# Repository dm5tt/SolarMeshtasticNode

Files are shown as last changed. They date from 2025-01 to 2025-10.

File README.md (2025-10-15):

**Warning:** 

This thing will get a big overhaul (better access to bus interfaces, improved outlines, etc.) as soon as the new TI BQ25630 charging controller will be released end of the year.  

The design will be much less complex  as we can get all power relevant data (solar/battery voltage, currents) by just querying the charger IC via I2C. 

Also the BOM will be much compacter as no voltage dividers will be need.

---

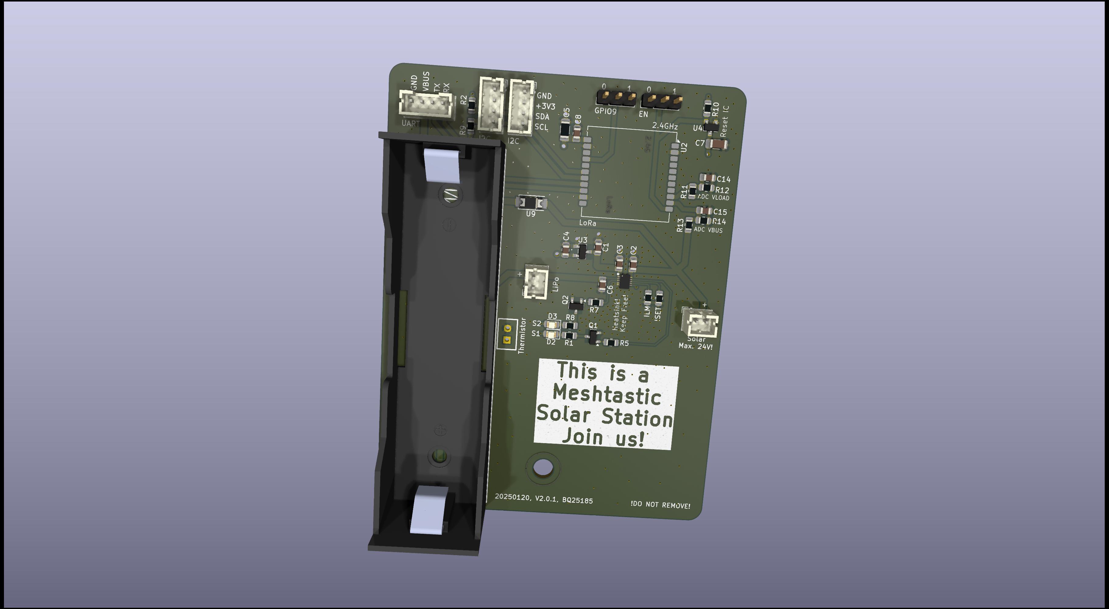
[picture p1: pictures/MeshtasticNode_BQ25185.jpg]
MeshtasticRouterNode


## What is this thing?

This is a Meshtastic solar node based on the [Heltec HT-CT62](https://resource.heltec.cn/download/HT-CT62/HT-CT62(Rev1.1).pdf) and the (new) linear solar charge controller [TI BQ25185](https://www.ti.com/lit/ds/symlink/bq25185.pdf).

Features of this PCB

 - Solar Input up to 18V (24V survival)
 - 3A maximum load
 - 1A maximum charge current
 - Pseudo-MPPT (VINDPM)
 - Power Path (= if the battery is fully charged and there's enough solar power the device is getting powered directly from solar. During sunrise and sunset it can mix the sources.)
 - Two ADC signals for getting VLOAD and  VBUS voltage using voltage dividers
 - 3.7V LiPo either via 18650 block or JST-PH 2.0 connector
 - Low power LDO [HEERMICR HE9073A30MR](https://www.lcsc.com/datasheet/lcsc_datasheet_2304140030_HEERMICR-HE9073A30MR_C723792.pdf)
 - Brown-out Reset IC ([Diodes Incorporated APX803L05-32SA-7](https://wmsc.lcsc.com/wmsc/upload/file/pdf/v2/lcsc/2304140030_Diodes-Incorporated-APX803L05-32SA-7_C2067928.pdf)) at 3.2V which senses the voltage *before* the LDO 

Combined with a solar panel this device can be placed in remote areas to cover a wide range.

*If you want to use the Reset IC*

Do not bridge the "EN" pin headers. The signal of this IC is "weak" -  it can be overruled by a jumper without destroying the board.

# Where can I get all the stuff?

Heltec HT-CT62: Aliexpress

TI BQ25185: Mouser or Digikey

PCB: You can load the Kicad project file and then export the manufacturing files using the plugins. Just throw them into JLCPCB and order them.

Everything else can be ordered from LCSC.

Due to strict legislation, it is not planned to offer ready-made circuit boards or kits here. Sorry.

# Meshtastic, ESP32 and Power Saving. How?

*Warning 1* 

By enabling "Power Saving" you will loose *all* regular telemetry (Sensors, Battery Voltages, etc.)! The battery voltage can be polled manually using the Python lib.

I reported this a bug but it was rejected.

*Warning 2* 

You also will not be able to configure it by serial port anymore! You have a short period after power cycling it. Use the "meshtastic" Python script as it waits for a while.

### Router Role

1. Enable "Power Saving" (is activated by default if using Router role)

2. When configuring the device you should set the "Minimum Wake Interval" from 10 seconds to 1 second.

3. Switch Bluetooth and Wifi off! They suck power like crazy.

### Client Role

This is more tricky as per default it doesn't switch into "Light Sleep" as several delays are blocking it.

You also have to decrease "Wait Bluetooth Seconds" and "Screen on Seconds" to 1 second.

Then configure is like a "Router".

# Do I have to modify the Software and configuration?

I'm keeping a more or less outdated branch von the Meshtastic firmware on `git@github.com:dm5tt/meshtastic-firmware.git` in the branch `solarmeshtasticnode`. If you want a fresher version you must rebase it yourself.

# Evaluation

[Evaluation, PCB v0.2 (CR123A)](./EVALUATION-v02.md)

[Evaluation, PCB v2.0.0 (18650)](./EVALUATION-v200.md)

# FAQ

*The HT-CT62 uses a ESP32C3. Thats not Low Power!!!*

Meshtastic  supports the "Power Saving" mode on the ESP32 where the entire   device stays  in the light sleep mode until it gets a interrupt signal from the LoRa modem. In that phase CPU will consume around ~800uA while sleeping. Including LoRa RX that's a idle current draw around is 5-6mA.

Warning, again: switching on BLE or even Wifi will make the ESP32 burn a crazy amount of energy. 

For sunny regions (Portugal, Spain, etc.) a 6V panel is enough. For central Europe (like Germany) a 12V or higher solar panel is recommended for surviving the winter.

Still far away from the RAK4631 with a Nordic microcontroller. But who cares? During the day you will have a positive power budget so the entire devices runs on solar energy and recharges its battery even with small cells.

*It's not really that cheap either!*

Yep. It's expensive if you build only 1 device. But the costs dramatically drop if think of building 5-10 of them as you can mass order everything (PCBs, Components from LCSC and so own).

*The TI BQ25185 uses a linear regulator to create the voltage before the LDO. That will be inefficient for solar panels above 6V.*

Yes. It's very inefficient if it's running with the power path enabled (= direct solar pass-through) as the device has to burn off a lot of voltage from the panel. During battery runtime the difference is way lower which is acceptable.

It maybe cause unneccesary heat during the winter time where small 18V solar panels would be a great benefit. But for 6V panels it's a within acceptable ranges.

I'm planing to build a new generation of the SolarMeshtasticNode with the upcoming [TI BQ25630](https://www.ti.com/lit/ds/symlink/bq25630.pdf?ts=1755932677893). It has an integrated ADC (which allows us to get rid of all power dividers) and also has a  very efficient DC DC buck architecture. Price wise it will be around $2 which is still very acceptable.

*Why are you using a 3.0V and not a 3.3V LDO?*

This gives us more runtime by only loosing 1-2dB TX power from the LoRa module.  

With a 3.3V LDO the device will switch off around ~3.5V - with 3.0V LDO it can survive down to 3.2V.

# Warning

LED circuit for STAT1 and STAT2 aren't tested. The TI BQ25185 uses 1.8V for the status pins so the LEDs must be switched via a transistor against the 3.3V supply voltage.

# License

CERN OHL v2 – Strongly Reciprocal (S)

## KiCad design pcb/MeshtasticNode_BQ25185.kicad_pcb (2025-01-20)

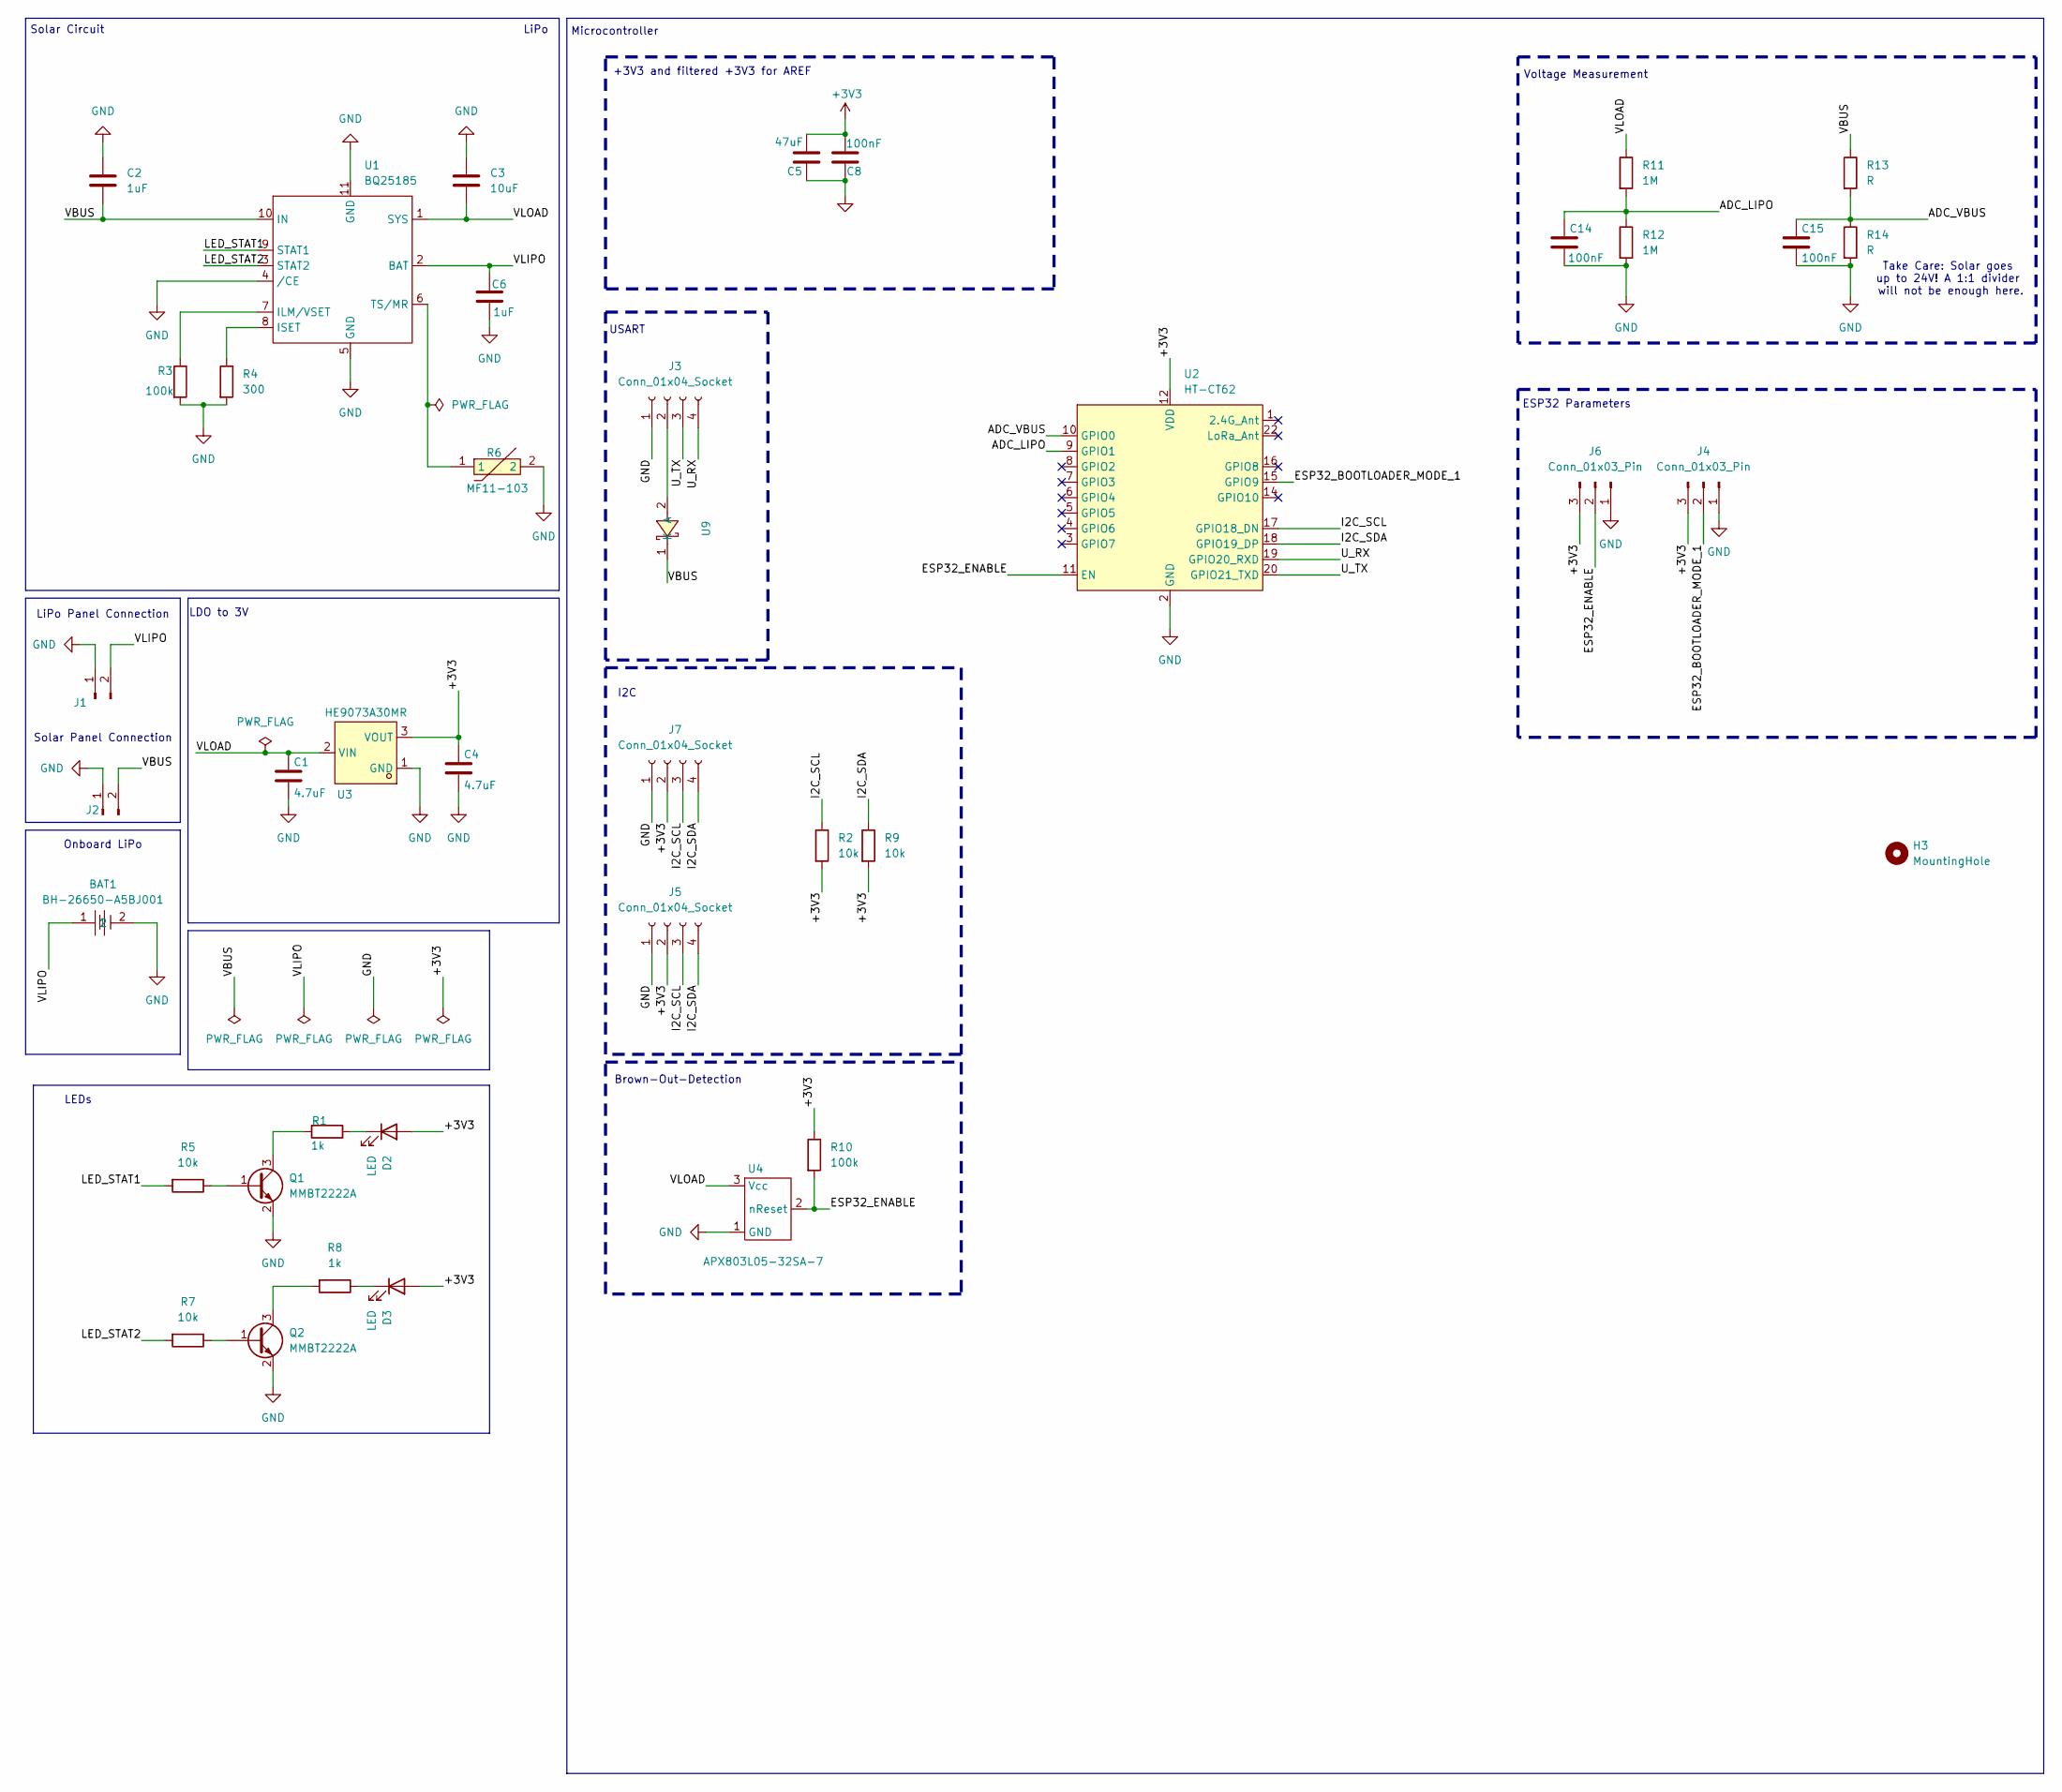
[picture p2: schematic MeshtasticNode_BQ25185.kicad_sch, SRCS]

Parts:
BAT1: BH-26650-A5BJ001; BAT-TH_BH-18650-A1AJ005; LCSC Part C6937119
C1, C4: 4.7uF; C_0805_2012Metric_Pad1.18x1.45mm_HandSolder
C2, C6: 1uF; C_0805_2012Metric_Pad1.18x1.45mm_HandSolder
C3: 10uF; C_0805_2012Metric_Pad1.18x1.45mm_HandSolder
C5: 47uF; R_1206_3216Metric_Pad1.30x1.75mm_HandSolder
C8, C14, C15: 100nF; C_0805_2012Metric_Pad1.18x1.45mm_HandSolder
D2, D3: LED; LED_0805_2012Metric_Pad1.15x1.40mm_HandSolder
H3: MountingHole; MountingHole_4.3mm_M4_DIN965
J1, J2: Conn_01x02_Socket; JST_PH_B2B-PH-K_1x02_P2.00mm_Vertical
J3, J5, J7: Conn_01x04_Socket; JST_PH_B4B-PH-K_1x04_P2.00mm_Vertical
J4, J6: Conn_01x03_Pin; PinHeader_1x03_P2.54mm_Vertical
Q1, Q2: MMBT2222A; SOT-23
R1, R8: 1k; R_0805_2012Metric_Pad1.20x1.40mm_HandSolder
R2, R5, R7, R9: 10k; R_0805_2012Metric_Pad1.20x1.40mm_HandSolder
R3, R10: 100k; R_0805_2012Metric_Pad1.20x1.40mm_HandSolder
R4: 300; R_0805_2012Metric_Pad1.20x1.40mm_HandSolder
R6: MF11-103; RES-TH_L6.5-W4.0-P2.50-D0.5; LCSC Part C70913
R11, R12: 1M; R_0805_2012Metric_Pad1.20x1.40mm_HandSolder
R13, R14: R; R_0805_2012Metric_Pad1.20x1.40mm_HandSolder
U1: BQ25185; SON40P220X200X80-11N
U2: HT-CT62; Heltec_HT-CT62
U3: HE9073A30MR; SOT-23-3_L2.9-W1.6-P1.90-LS2.8-BR-CW; LCSC Part C723793
U4: APX803L05-32SA-7; SOT23-3
U9: SS26_C5350986; SMA_L4.3-W2.6-LS5.1-RD; LCSC Part C5350986

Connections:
+3V3: C4.1, C5.2, C8.2, D2.2 (A), D3.2 (A), J4.3, J5.2, J6.3, J7.2, R2.2, R9.2, R10.1, U2.12 (VDD), U3.3 (VOUT)
/ADC_LIPO: C14.1, R11.2, R12.1, U2.9 (GPIO1)
/ADC_VBUS: C15.1, R13.2, R14.1, U2.10 (GPIO0)
/ESP32_BOOTLOADER_MODE_1: J4.2, U2.15 (GPIO9)
/ESP32_ENABLE: J6.2, R10.2, U2.11 (EN), U4.2 (nReset)
/I2C_SCL: J5.3, J7.3, R2.1, U2.17 (GPIO18_DN)
/I2C_SDA: J5.4, J7.4, R9.1, U2.18 (GPIO19_DP)
/LED_STAT1: R5.2, U1.9 (STAT1)
/LED_STAT2: R7.2, U1.3 (STAT2)
/U_RX: J3.4, U2.19 (GPIO20_RXD)
/U_TX: J3.3, U2.20 (GPIO21_TXD)
/VBUS: C2.2, J2.2, R13.1, U1.10 (IN), U9.1 (K)
/VLIPO: BAT1.1, C6.1, J1.2, U1.2 (BAT)
/VLOAD: C1.1, C3.2, R11.1, U1.1 (SYS), U3.2 (VIN), U4.3 (Vcc); also elsewhere on the board
GND: BAT1.2, C1.2, C2.1, C3.1, C4.2, C5.1, C6.2, C8.1, C14.2, C15.2, J1.1, J2.1, J3.1, J4.1, J5.1, J6.1, J7.1, Q1.2 (E), Q2.2 (E), R3.2, R4.2, R6.2, R12.2, R14.2, U1.4 (/CE), U1.5 (GND), U1.11 (GND), U2.2 (GND), U2.13 (GND), U2.21 (GND), U3.1 (GND), U4.1 (GND); also elsewhere on the board
unnamed: D2.1 (K), R1.1
unnamed: D3.1 (K), R8.1
unnamed: J3.2, U9.2 (A)
unnamed: Q1.1 (B), R5.1
unnamed: Q1.3 (C), R1.2
unnamed: Q2.1 (B), R7.1
unnamed: Q2.3 (C), R8.2
unnamed: R3.1, U1.7 (ILM/VSET)
unnamed: R4.1, U1.8 (ISET)
unnamed: R6.1, U1.6 (TS/MR)

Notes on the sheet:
ESP32 Parameters
Solar Circuit
Microcontroller
USART
Voltage Measurement
LiPo
LiPo Panel Connection
+3V3 and filtered +3V3 for AREF
Brown-Out-Detection
Onboard LiPo
Solar Panel Connection
LDO to 3V
I2C
Take Care: Solar goes up to 24V! A 1:1 divider will not be enough here.
LEDs

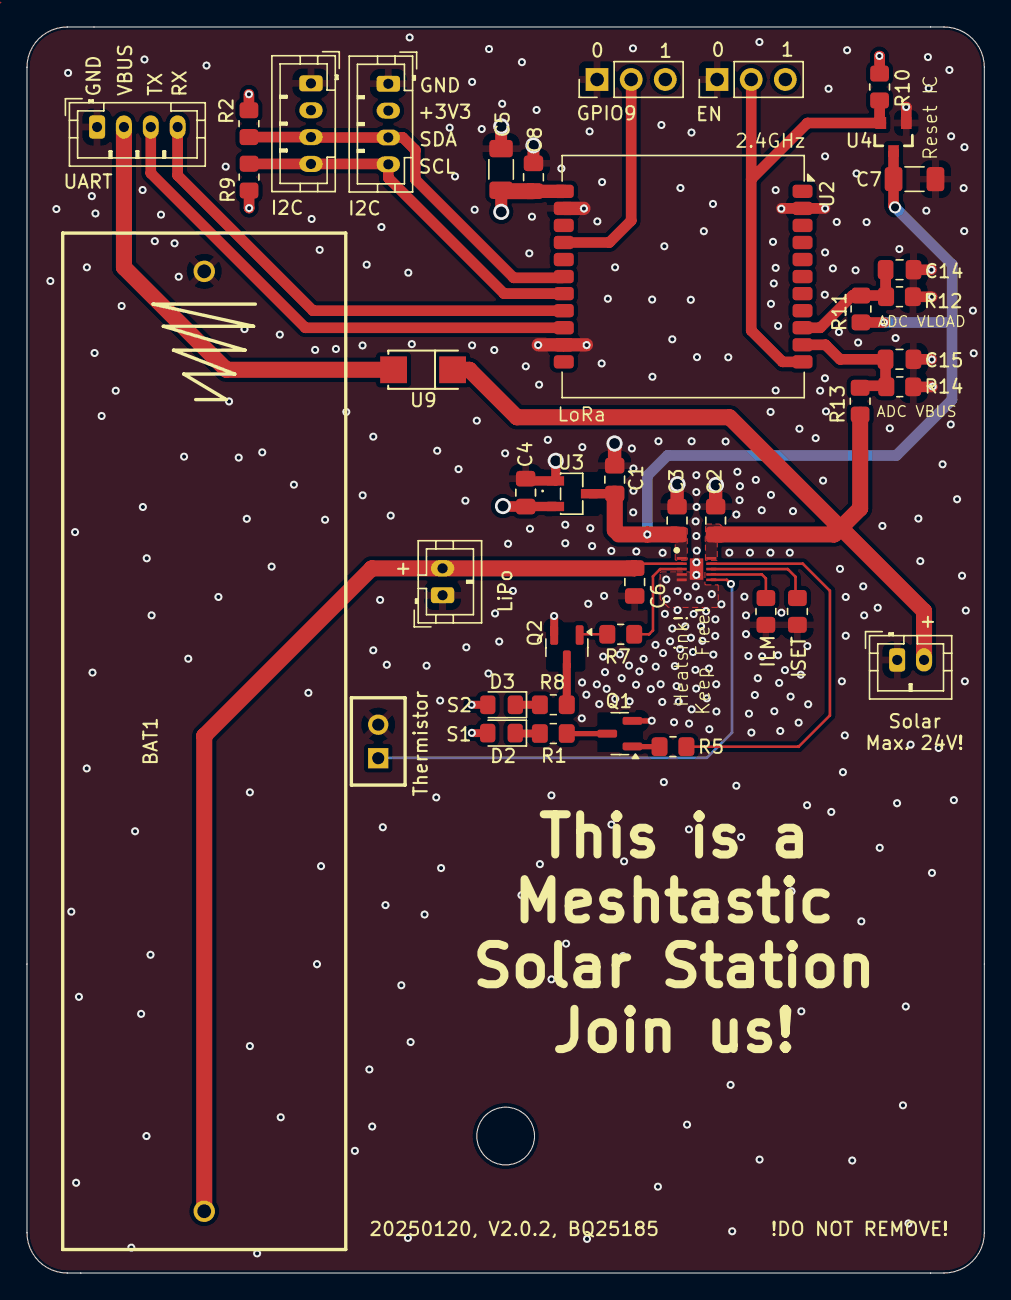
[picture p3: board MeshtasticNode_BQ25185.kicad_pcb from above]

Board: 4 copper layers, 71.3 x 92.8 mm, 42 parts (0 on the bottom side), 25 nets.

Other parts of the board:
C7: 22uF; C_1206_3216Metric_Pad1.33x1.80mm_HandSolder

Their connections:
/VLOAD: C7.2; also elsewhere on the board
GND: C7.1; also elsewhere on the board

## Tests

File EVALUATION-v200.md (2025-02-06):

# Evaluation SolarMeshtasticNode PCB v2.0.0

Meshtastic Node The DUT

## Setup

- Antenna: 5dBi omnidirectional, resonant on 868MHz
- Battery: KeePower, 4000mA, 3.7V, PartNo.  P1840C
- Solar: 9V, 400mA, Noname product from Aliexpress
- End of charge voltage: 4.2V
- Meshtastic Git Hash: f18a92e8c5be5a483a47b97adc58886808b12fc5 + Pin modifications 

LEDs S1/S2 and their transistors haven't been placed as I don't need them.

No sensors added.

# Meshtastic Configuration

- Role: CLIENT
- Power Saving: Disabled  (!)
- Telemetry rate: 1h

Other settings are default.

# Picture of the integrated PCB

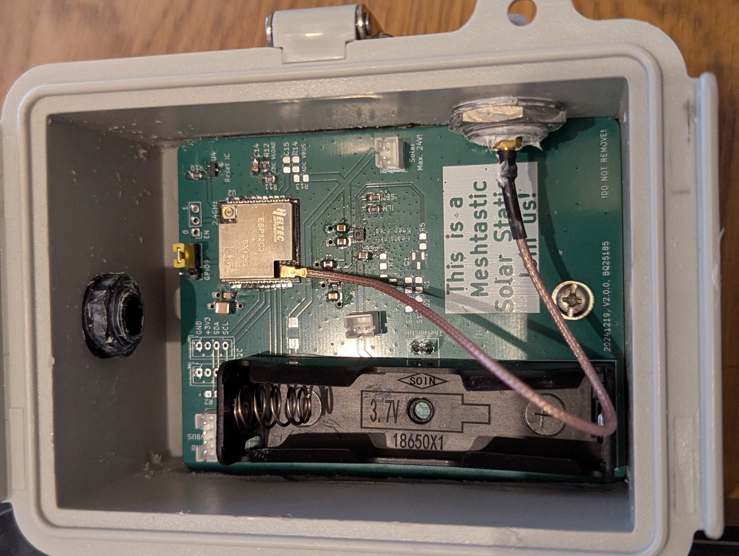
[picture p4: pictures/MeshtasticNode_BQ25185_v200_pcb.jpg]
Meshtastic Node PCB in the box


# Picture of the entire device

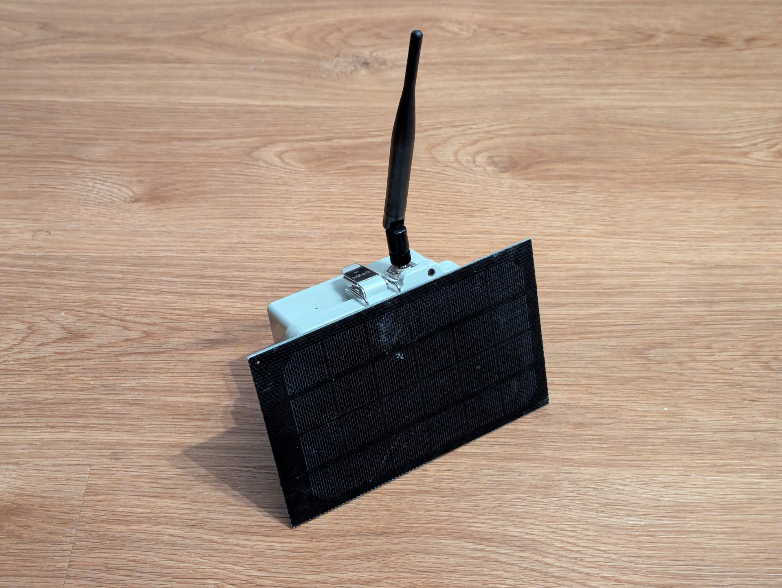
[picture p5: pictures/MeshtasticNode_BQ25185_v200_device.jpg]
Meshtastic Node Entire System


# Power consumption (Grafana)

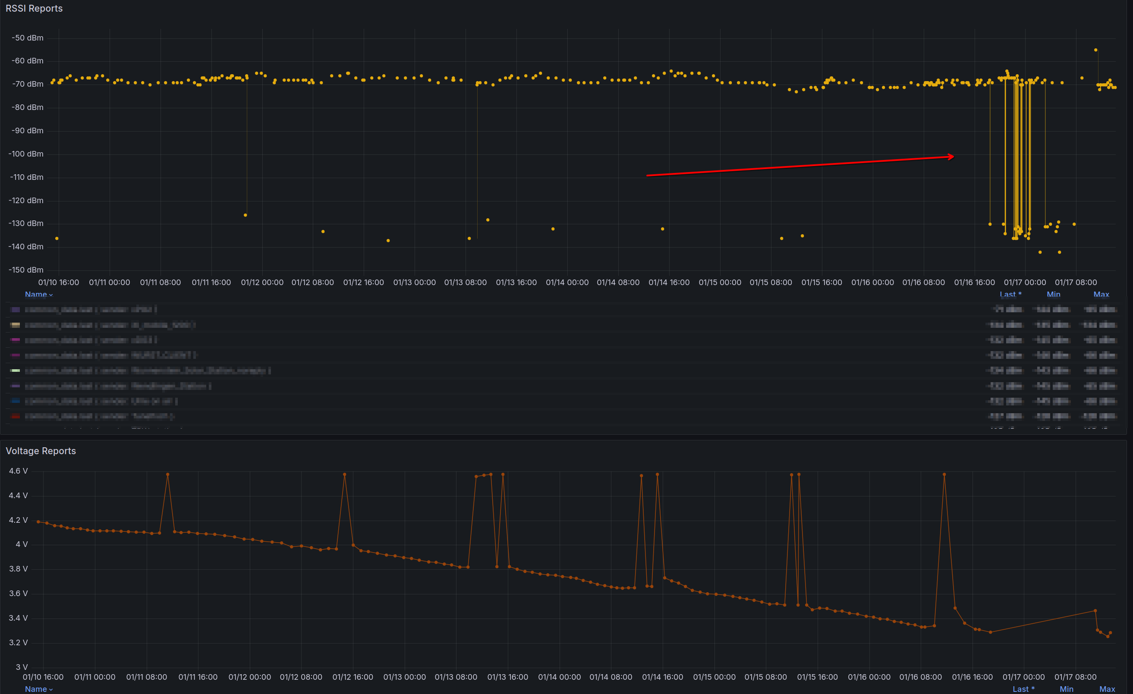
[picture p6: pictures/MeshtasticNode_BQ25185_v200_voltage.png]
Meshtastic Node Voltage Plot


Analyzing the battery voltage and beacons during a low-sunlight scenario showed that there's a problem with the Reset IC: it's bouncing around the 3.2V.  As a fix  a 1uF capacitor was added directly next to the  sensing pin of the IC.

Testing continues.

# Lessons learned

Pretty mutch all construction things from the last tested version (v0.2) still apply and turned out be be very successful. Especially using the solar panel as sun shield with ~4mm plastic spacers keeps the system temperature low - even during the summer time.

Switching the battery type 18650 standard blocks was also a good decision. This reduced costs a lot and increased the overall storage capacity dramatically as they have trustable datasheets.

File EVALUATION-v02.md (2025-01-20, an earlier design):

# Evaluation of the v0.2

## Case

Meshtastic Node The setup

Lessons learned: 

  - Use 5-6mm spacers between the solar panel and the box. It indirectly can act as a sunshield. As solar panels are mostly black they heat up a lot and so shouldn't be directly attached to it.
  - White or silver spray reduces the temperature even more. Bonus if it's a highly reflective spray.
  - Gore venting plugs are very expensive but useful to control the humidity. Not overly  critical as long it's only normal water - but salty air like close to the ocean kills electronics. EDIT: Alternative to Gore venting plugs: you can use syringe filters! They are cheap (100pcs@20€ at Aliexpress) with 0.8um pores.
  - Never use any hot glue. I switched to polymer adhesives used for boats and pools. A slight residual elasticity is desirable as it prevents breakage due to cable movement.

## Electronics

Meshtastic Integration

Lessons learned:

 - Voltage dividers with 1M:1M and a 100nF puffer C works perfectly fine. The power drain is below the battery self discharge level and the ESP32 ADC is able to sample the voltage without getting too much noise.

 - The crappy ESP32 ADC isn't super precise. Known issue.

 - For panels up to ~6V the TI BQ25185 seems to be the right decision
   - It will get very hot at higher voltage levels because of its linear design. That inefficient and also bad for low temperature soldering paste.  
   - The end-of-charge voltage can be reduced in several steps to extend the battery life
   - Power path'ing switches the battery off if sunlight is enough to power the device. It's also able to mix both sources
   - Pseudo MPPT (VINDPM) always gets us the maximum amount of current out of the solar panel

- Don't use CR123A batteries. They are non-standard for 3.7V LiPos and there are a lot of fakes around. The missing market makes them very expensive.
   - Go for the standard LiPo battery size 18650 or even 21700

- The ESP32C3 can be thamed in terms of current consumption. But let's be honest: it's not a Nordic or STM32U0.
  - Stay in light sleep as much as possible (theoretically ~600-800uA) and wake up by interrupts
  - Avoid BLE or Wifi at all costs

- Most power drain will be the LoRa module which sucks ~2-4mA during passive RX

 ## Measurements

For a real world test I setup following hardware configuration:

 - ISET = 300Ohm: Solar current of 1A 
 - ILM = 100kOhm: Maximum charging voltage 4.1V@1100mA
 - Noname ~800mAh 3.7V CR123A LiPo
 - 6V 290mAh solar cell

 Meshtastic configuration:

  - Minimum Wake Interface: 1s (default: 10s)
  - Repeater Mode activated
  - BLE/Wifi disabled (configuration via UART)

 Syytem configuration:
  - ESP32C3 CPU speed reduced to 80MHz

The telemetry values are getting pulled from the device every 30 minutes and then getting stored into an InfluxDB which are getting visualized using Grafana.

Our Meshtastic network (Stuttgart/Germany) has around 22-50 users.

Meshtastic Grafana

Description

1. Sun gone. The power path circuit disables direct powering from the solar cell. 
2. Discharge process over night
3. First sunlight. Battery charging starts.
4. Battery full. Power Path circuit disables the battery and switches to direct pass-through.

Using that graph the maximum survival time of the device without sunlight an be calculated.

- Start voltage, night: 4.1V

- Stop voltage, early morning: 4.04V

- Assumed hard switch-off voltage: 3.4V

- Duration: 12h

This leads to an average remaining battery run time of theoretically 128h (5.3 days). Pratically this would be more around 3-4 full days.

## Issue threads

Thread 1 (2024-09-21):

If power supply of the LDO drops too low it collapes immediately - too fast for the Brown-Out-Detection to trigger

dm5tt, 2024-09-21:
If the power supply of  3.3V LDO after the BQ25185 drops below ~3.4V it collapses almost immediately. The ESP32 brown-out-detection is too slow to react. This can and will cause file system corruption during early boot phases of the Meshtastic firmware if this happen during a write.

**Solution**

Add a Reset-IC before the LDO (as this is the Solar+LiPo voltage mix) and disable EN if we are dropping too low.

dm5tt, 2024-10-14:
I think this problem can easily be solved: Replace the 3V3  with a 3V0 LDO so the entire device can stay alive much longer. With the the "Low Power" detection of Meshtastic (that uses the ADC) can safely put the ESP32 into a safe deep sleep mode.

dm5tt, 2024-10-27:
Fixed with V1.0

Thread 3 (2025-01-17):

Reset IC triggers  too often around 3.2V

dm5tt, 2025-01-17:
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

Potential solutions:

1. Get a different Reset IC that waits for 1-2 seconds
2. Add a C to buffer the voltage
3. Add a proper filter

Testing solution 2. now.

dm5tt, 2025-01-18:
Added a 1uF capacitor directly next to the Reset-IC Vcc and its GND. Test running.

dm5tt, 2025-01-20:
Temporary fix in v2.0.1

Closed 2025-01-20.

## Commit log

2024-12-29 pcb: remove test pin nobody ever used
    [MeshtasticNode_BQ25185.kicad_pcb, MeshtasticNode_BQ25185.kicad_sch]
2024-12-29 symbols: add APX803L05-32SA-7 (3.2v brown out detector)
2024-12-29 pcb, sch: add brown out (3.2v) detector
    [MeshtasticNode_BQ25185.kicad_pcb, MeshtasticNode_BQ25185.kicad_sch]
2024-12-29 pcb: several changes
    - Make PCB 2mm smaller. Allows us to use cheaper boxes from Aliexpress.
    - Add a 3.2V Reset IC
    [MeshtasticNode_BQ25185.kicad_pcb]
2024-12-29 pcb: Eye candy changes
    [MeshtasticNode_BQ25185.kicad_pcb]
2025-01-06 README: add detail regarding how to still poll battery voltages
2025-01-06 README: be even more detailed about getting the voltage
2025-01-06 pcb: fix some smaller DRC errors and eye candy issues
    [MeshtasticNode_BQ25185.kicad_pcb]
2025-01-18 EVALUATION-v200: a lie - it's a 1uf capacitor
2025-01-20 pcb, sch: add C in front of Reset IC sensing line
    [MeshtasticNode_BQ25185.kicad_pcb, MeshtasticNode_BQ25185.kicad_sch]
2025-01-20 pcb: non functional eye candy changes
    [MeshtasticNode_BQ25185.kicad_pcb]
2025-05-20 pcb: replace button
    [MeshtasticNode_BQ25185.kicad_sch]
2025-05-20 Revert "pcb: replace button" - Worked on wrong repo by accident
    This reverts commit de6b8aef5b6993324b841dd2494786c25740dc74.
    [MeshtasticNode_BQ25185.kicad_sch]
2025-08-03 README: be more verbose about the "Power Path" and fix some formattings
2025-08-23 README: be more precise about power consumption
2025-08-23 README: add info with redesign with DCDC charge controller
